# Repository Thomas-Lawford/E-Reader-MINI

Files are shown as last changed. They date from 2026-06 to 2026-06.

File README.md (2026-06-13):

Solar Powered E-Reader Keychain 

Has a custom E-Paper driver circuit MicroSD card interface and solar energy harvesting circuit.

Based on the STM32U073 with sub 1 μW operational power consumption.

Has a custom FILEX implementation that supports EXfat and fat32 file systems (Supports SDUC, SDXC and SDHC), 3d printed Case design and a custom EPD lookup table for the 1.22 inch E paper display.

Power consumption is so low this design is battery free with a supercap to store charge for brief current spikes from microSD card reads.
 
 You can select a text file to read, jump to a specific page, and adjust the font size
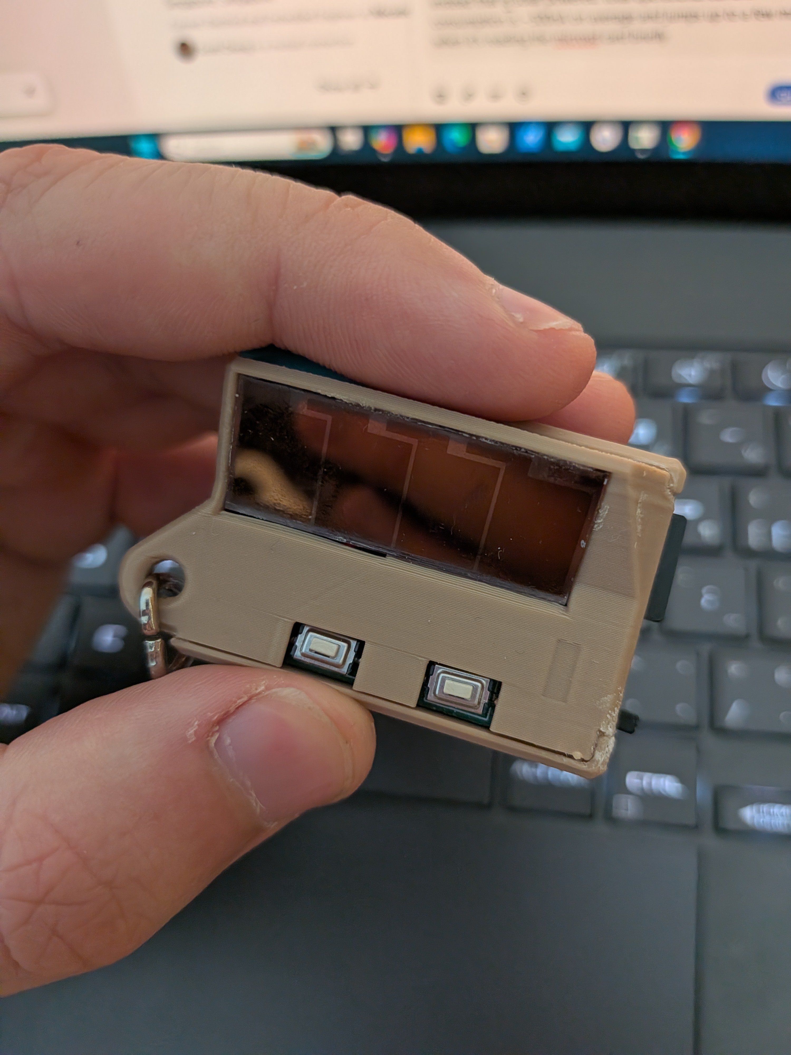
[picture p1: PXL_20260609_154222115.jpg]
back of device
 
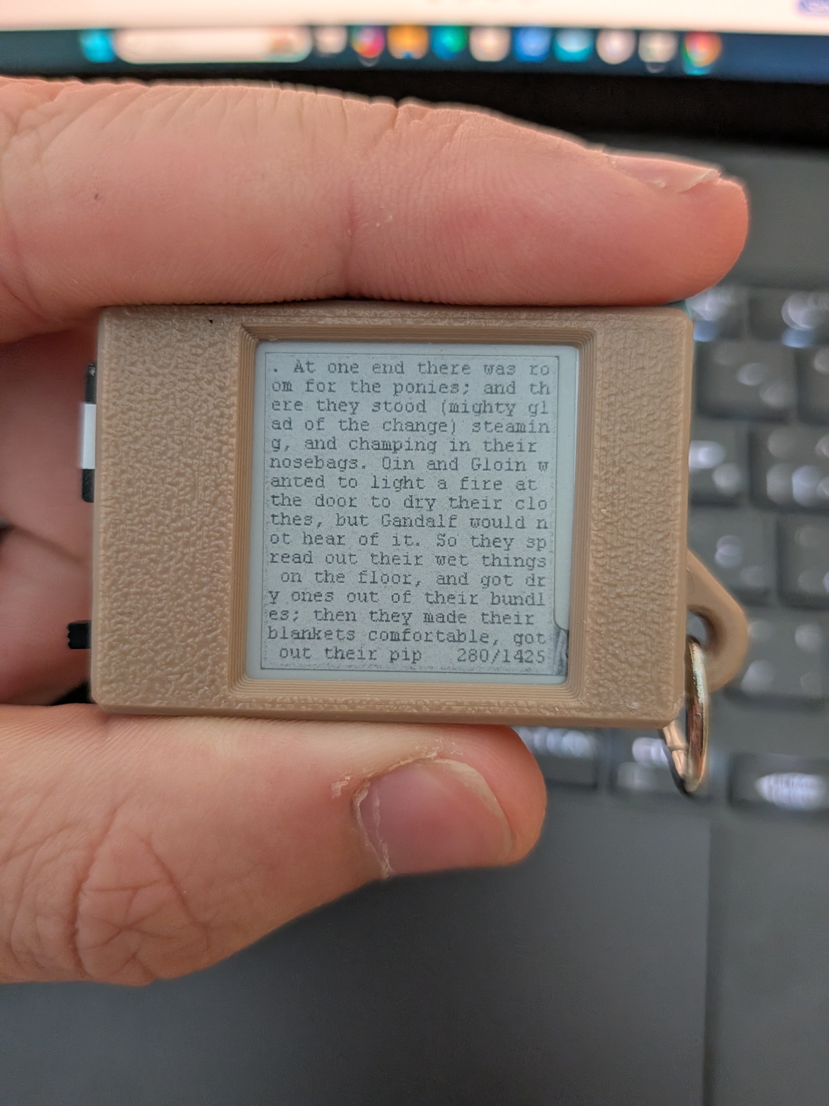
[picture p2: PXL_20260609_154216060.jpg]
front of device
 
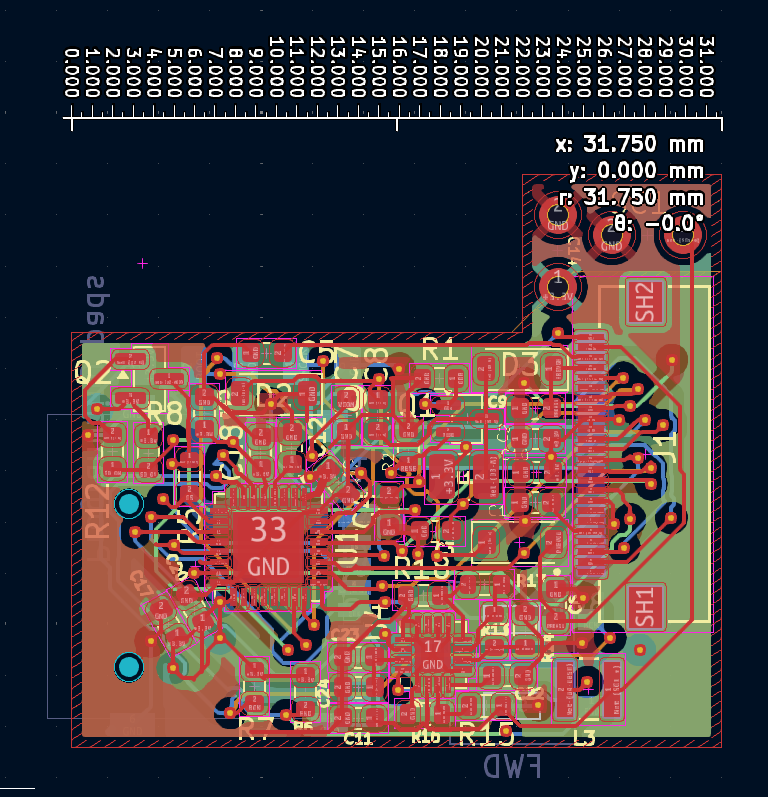
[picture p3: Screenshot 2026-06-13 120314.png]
PCB design


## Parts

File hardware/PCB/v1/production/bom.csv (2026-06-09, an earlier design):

Designator | Footprint | Quantity | Value | LCSC Part #
C1, C2, C3, C4, C5, C6, C7, C9 | 0603 | 8 | 1u 25v x5r/x7r
C10, C8 | 0603 | 2 | 4.7u 25v x5r/x7r
C11, C17, C24 | 0603 | 3 | 4.7uF
C12, C20, C21, C23 | 0603 | 4 | 100nf
C14 | 25F 3.8V cap | 1 | 25F
C18, C22 | 0603 | 2 | 10nf
C19 | 0603 | 1 | 1uf
D1, D2, D3 | D_SOD-123 | 3 | MBR0530
D4 | 0805 | 1 | LED
J1 | AMPHENOL_F33Z-1A7Q1-E8C24 | 1 | Conn_01x24_MountingPin
J2 | CONN9_MSD-4-A_SSD | 1 | Micro_SD_Card
J4 | 4_p_SWD_prog | 1 | Programming pads
L1 | 1008 | 1 | 4.7u 500mA
L3 | IND_ASPI-0315FS-220M-T2 | 1 | 22uh
Q1 | SOT-323_SC-70 | 1 | Si1308EDL
Q2 | SOT-23 | 1 | PMOS
R1 | 0603 | 1 | 1M
R12, R6, R7 | 0603 | 3 | 150k
R13 | 0603 | 1 | 4.75M
R14 | 0603 | 1 | 5.49M
R15 | 0603 | 1 | 8M
R16 | 0603 | 1 | 12M
R17 | 0603 | 1 | 5.1M
R18 | 0603 | 1 | 4.75
R2, R3 | 0603 | 2 | 2.2M
R4, R8 | 0603 | 2 | 220
R5 | 0603 | 1 | 20k
SC1 | 25F 3.8V cap | 1 | Solar_Cell
SW1 | SW_Tactile_SPST_NO_Straight_CK_PTS636Sx25SMTRLFS | 1 | BCK
SW3 | SW_Tactile_SPST_NO_Straight_CK_PTS636Sx25SMTRLFS | 1 | FWD
SW4 | SW_SLW-864574-5A-RA-N-D | 1 | SW_SPST
U1 | QFN-32-1EP_5x5mm_P0.5mm_EP3.45x3.45mm | 1 | STM32U073K8Ux
U4 | VQFN-16-1EP_3x3mm_P0.5mm_EP1.68x1.68mm | 1 | BQ25504

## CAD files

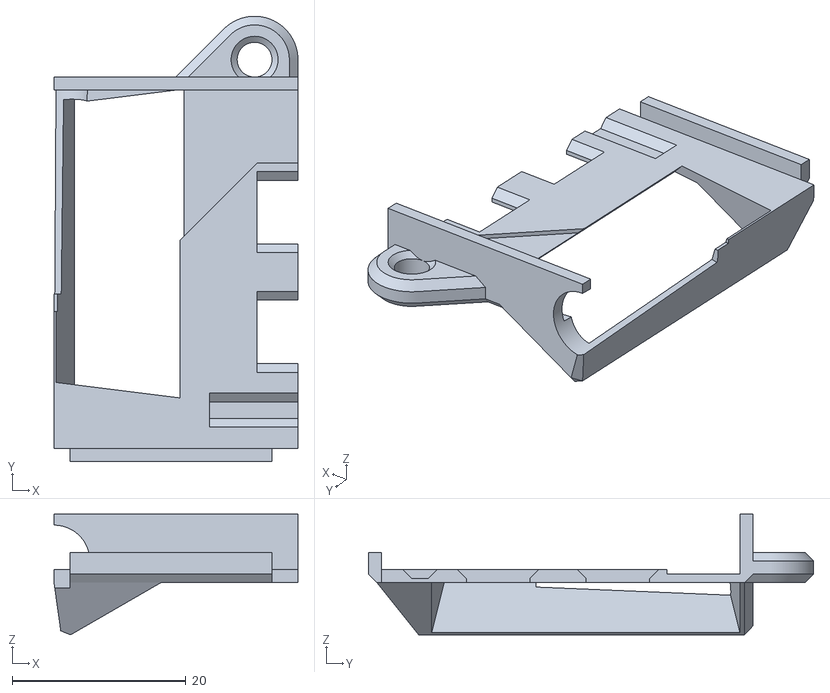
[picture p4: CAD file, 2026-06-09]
hardware/Case/v1/rear cover.stl
28.1 x 51.3 x 13.9

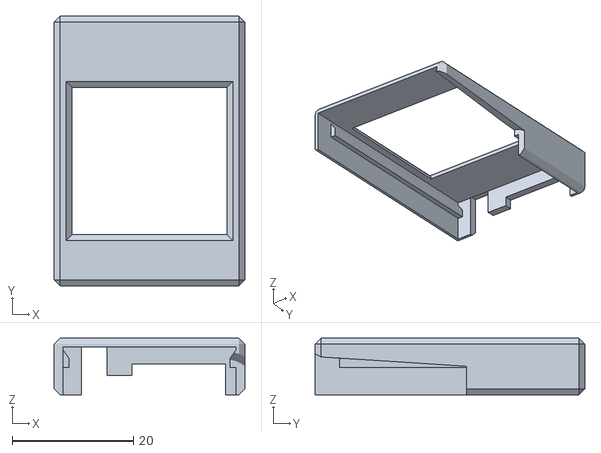
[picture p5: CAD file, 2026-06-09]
hardware/Case/v1/front cover.stl
31.5 x 44.5 x 9.40

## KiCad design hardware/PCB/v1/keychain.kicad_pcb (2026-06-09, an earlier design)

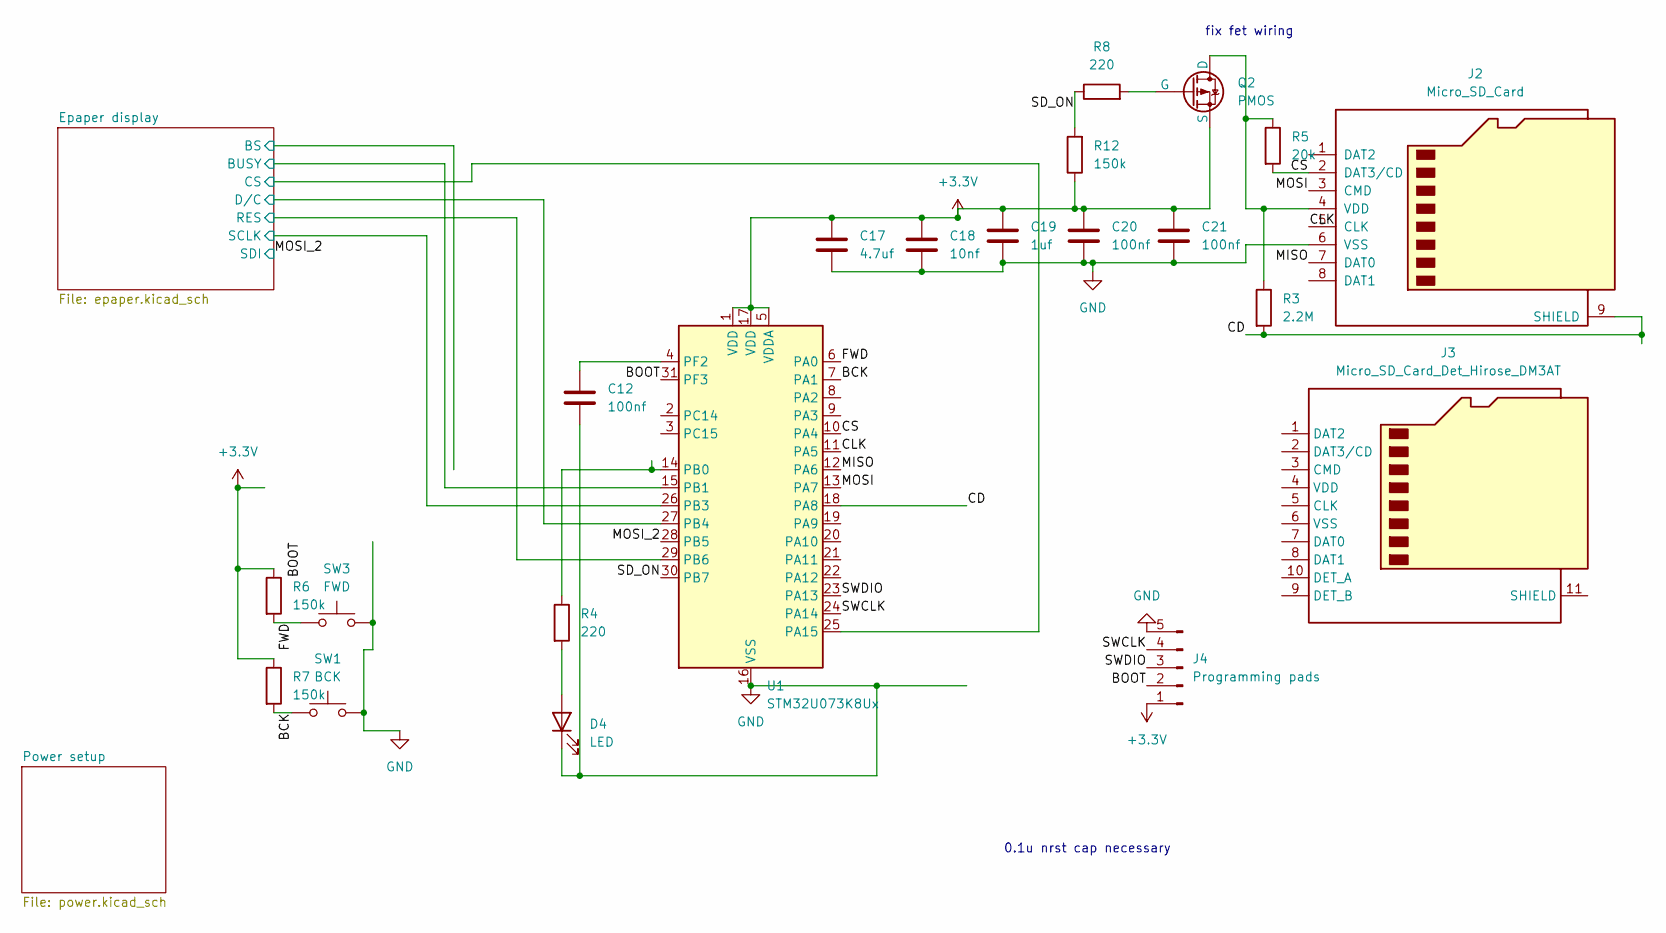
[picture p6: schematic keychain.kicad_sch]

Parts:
C12, C20, C21: 100nf; C_0603_1608Metric
C17: 4.7uf; C_0603_1608Metric
C18: 10nf; C_0603_1608Metric
C19: 1uf; C_0603_1608Metric
D4: LED; LED_0805_2012Metric
J2: Micro_SD_Card; CONN9_MSD-4-A_SSD
J3: Micro_SD_Card_Det_Hirose_DM3AT
J4: Programming pads; 4_p_SWD_prog
Q2: PMOS; SOT-23
R3: 2.2M; R_0603_1608Metric
R4, R8: 220; R_0603_1608Metric
R5: 20k; R_0603_1608Metric
R6, R7, R12: 150k; R_0603_1608Metric
SW1: BCK; SW_Tactile_SPST_NO_Straight_CK_PTS636Sx25SMTRLFS
SW3: FWD; SW_Tactile_SPST_NO_Straight_CK_PTS636Sx25SMTRLFS
U1: STM32U073K8Ux; QFN-32-1EP_5x5mm_P0.5mm_EP3.45x3.45mm

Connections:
+3.3V: C17.1, C18.1, C19.1, C20.1, C21.1, J4.1, Q2.3 (S), R6.1, R7.1, R12.1, U1.1 (VDD), U1.5 (VDDA), U1.17 (VDD); also elsewhere on the board
/BCK: R7.2, SW1.1, U1.7 (PA1)
/BOOT: J4.2, U1.31 (PF3)
/CD: J2.9 (SHIELD), R3.2, U1.18 (PA8)
/CLK: J2.5 (CLK), U1.11 (PA5)
/CS: J2.2 (DAT3/CD), R5.2, U1.10 (PA4)
/Epaper display/BUSY: U1.15 (PB1); also elsewhere on the board
/Epaper display/CS: U1.25 (PA15); also elsewhere on the board
/Epaper display/D/C: U1.27 (PB4); also elsewhere on the board
/Epaper display/RES: U1.29 (PB6); also elsewhere on the board
/Epaper display/SCLK: U1.26 (PB3); also elsewhere on the board
/FWD: R6.2, SW3.1, U1.6 (PA0)
/MISO: J2.7 (DAT0), U1.12 (PA6)
/MOSI: J2.3 (CMD), U1.13 (PA7)
/MOSI_2: U1.28 (PB5); also elsewhere on the board
/SD_ON: R8.1, R12.2, U1.30 (PB7)
/SWCLK: J4.4, U1.24 (PA14)
/SWDIO: J4.3, U1.23 (PA13)
GND: C12.2, C17.2, C18.2, C19.2, C20.2, C21.2, D4.1 (K), J2.6 (VSS), J4.5, SW1.2, SW3.2, U1.16 (VSS), U1.32 (VSS), U1.33 (VSS); also elsewhere on the board
unnamed: D4.2 (A), R4.2
unnamed: J2.4 (VDD), Q2.1 (D), R3.1, R5.1
unnamed: Q2.2 (G), R8.2
unnamed: R4.1, U1.14 (PB0)
unnamed: C12.1, U1.4 (PF2)

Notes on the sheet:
fix fet wiring
0.1u nrst cap necessary

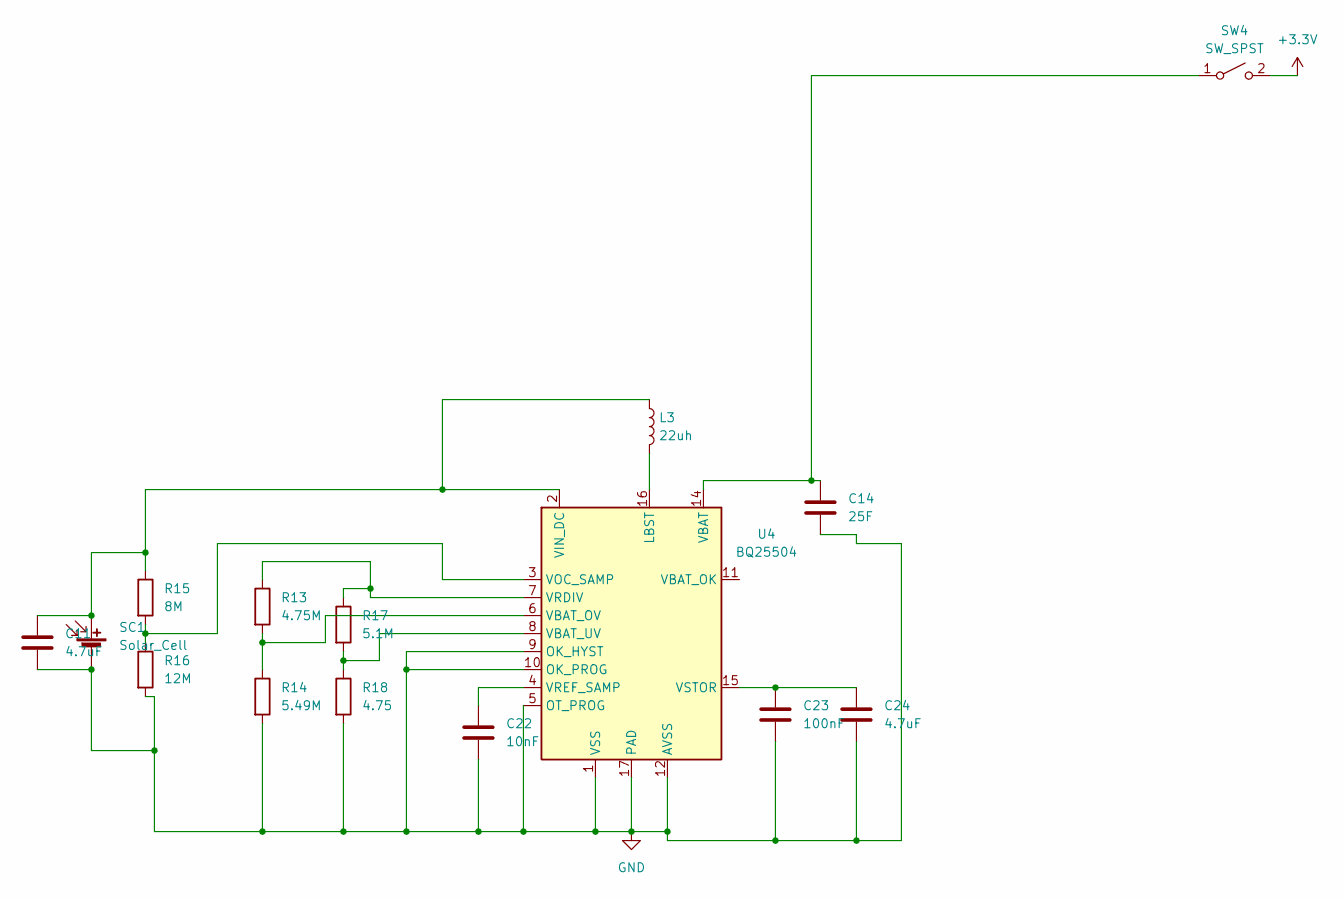
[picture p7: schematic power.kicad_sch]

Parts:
C11, C24: 4.7uF; C_0603_1608Metric
C14: 25F; 25F 3.8V cap
C22: 10nF; C_0603_1608Metric
C23: 100nF; C_0603_1608Metric
L3: 22uh; IND_ASPI-0315FS-220M-T2
R13: 4.75M; R_0603_1608Metric
R14: 5.49M; R_0603_1608Metric
R15: 8M; R_0603_1608Metric
R16: 12M; R_0603_1608Metric
R17: 5.1M; R_0603_1608Metric
R18: 4.75; R_0603_1608Metric
SC1: Solar_Cell; 25F 3.8V cap
SW4: SW_SPST; SW_SLW-864574-5A-RA-N-D
U4: BQ25504; VQFN-16-1EP_3x3mm_P0.5mm_EP1.68x1.68mm

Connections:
+3.3V: SW4.2 (B); also elsewhere on the board
GND: C11.2, C14.2, C22.2, C23.2, C24.2, R14.2, R16.2, R18.2, SC1.2 (-), U4.1 (VSS), U4.5 (OT_PROG), U4.9 (OK_HYST), U4.10 (OK_PROG), U4.12 (AVSS), U4.13 (VSS), U4.17 (PAD); also elsewhere on the board
unnamed: C11.1, L3.1, R15.1, SC1.1 (+), U4.2 (VIN_DC)
unnamed: C14.1, SW4.1 (A), U4.14 (VBAT)
unnamed: L3.2, U4.16 (LBST)
unnamed: R13.2, R14.1, U4.6 (VBAT_OV)
unnamed: R17.2, R18.1, U4.8 (VBAT_UV)
unnamed: R15.2, R16.1, U4.3 (VOC_SAMP)
unnamed: R13.1, R17.1, U4.7 (VRDIV)
unnamed: C22.1, U4.4 (VREF_SAMP)
unnamed: C23.1, C24.1, U4.15 (VSTOR)

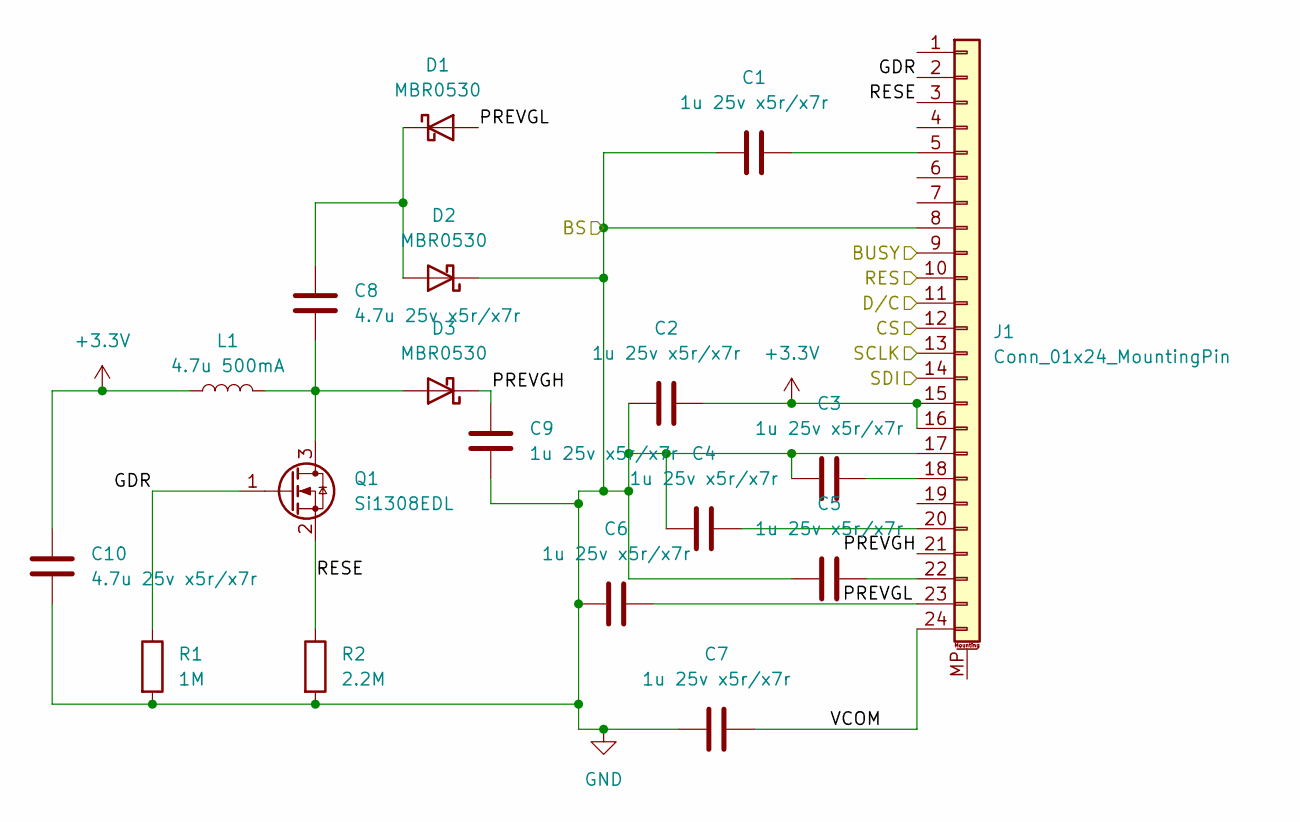
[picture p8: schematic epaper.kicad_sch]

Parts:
C1, C2, C3, C4, C5, C6, C7, C9: 1u 25v x5r/x7r; C_0603_1608Metric
C8, C10: 4.7u 25v x5r/x7r; C_0603_1608Metric
D1, D2, D3: MBR0530; D_SOD-123
J1: Conn_01x24_MountingPin; AMPHENOL_F33Z-1A7Q1-E8C24
L1: 4.7u 500mA; L_1008_2520Metric
Q1: Si1308EDL; SOT-323_SC-70
R1: 1M; R_0603_1608Metric
R2: 2.2M; R_0603_1608Metric

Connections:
+3.3V: C2.2, C10.2, J1.15, J1.16, L1.1; also elsewhere on the board
/Epaper display/BUSY: J1.9; also elsewhere on the board
/Epaper display/CS: J1.12; also elsewhere on the board
/Epaper display/D/C: J1.11; also elsewhere on the board
/Epaper display/GDR: J1.2, Q1.1 (G), R1.1
/Epaper display/PREVGH: C9.2, D3.1 (K), J1.21
/Epaper display/PREVGL: C6.2, D1.2 (A), J1.23
/Epaper display/RES: J1.10; also elsewhere on the board
/Epaper display/RESE: J1.3, Q1.2 (S), R2.1
/Epaper display/SCLK: J1.13; also elsewhere on the board
/Epaper display/VCOM: C7.2, J1.24
/MOSI_2: J1.14; also elsewhere on the board
GND: C1.1, C2.1, C3.1, C4.1, C5.1, C6.1, C7.1, C9.1, C10.1, D2.1 (K), J1.8, J1.17, R1.2, R2.2; also elsewhere on the board
unnamed: C8.1, D1.1 (K), D2.2 (A)
unnamed: C8.2, D3.2 (A), L1.2, Q1.3 (D)
unnamed: C1.2, J1.5
unnamed: C3.2, J1.18
unnamed: C4.2, J1.20
unnamed: C5.2, J1.22

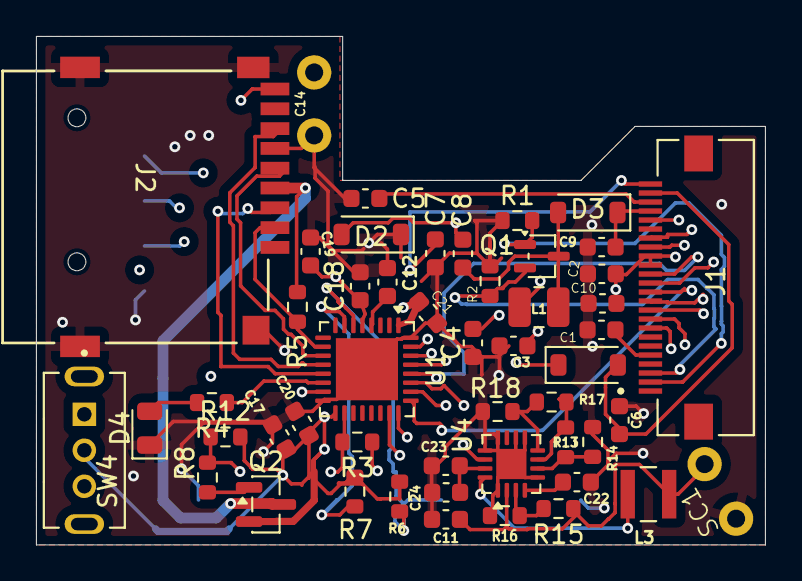
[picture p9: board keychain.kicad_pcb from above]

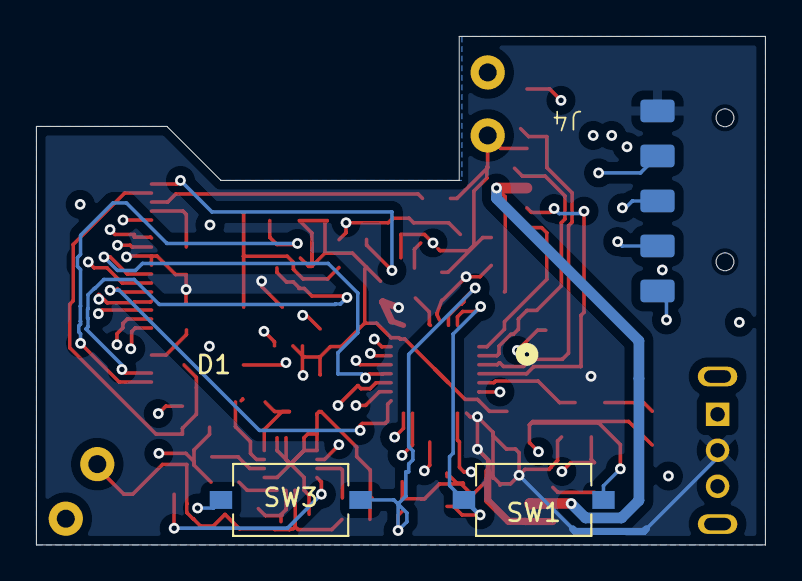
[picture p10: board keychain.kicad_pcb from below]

Board: 4 copper layers, 40.5 x 28.2 mm, 53 parts (3 on the bottom side), 44 nets.

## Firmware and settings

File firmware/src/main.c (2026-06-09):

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
/* Includes ------------------------------------------------------------------*/
#include "main.h"
#include "app_filex.h"

/* USER CODE BEGIN Includes */
#include "EPD/Display_EPD_W21.h"
#include "EPD/Display_EPD_W21_spi.h"
#include "GUI/GUI_Paint.h"
#include "Fonts/fonts.h"
//#include "fatfs.h"
//#include "spi.h"
//#include "sd_filereader.h"
#include "stdio.h"
//#include "sd_spi.h"
/* USER CODE END Includes */

/* USER CODE BEGIN PTD */
#define IMAGE_SIZE (EPD_WIDTH * EPD_HEIGHT / 8)
UBYTE ImageBuffer[IMAGE_SIZE];
/* USER CODE END PTD */

/* USER CODE BEGIN PD */
#define NDEBUG

// If using HAL, disable assert_param checks
#define USE_FULL_ASSERT 0
#define PVD_THRESHOLD_LEVEL  PWR_PVDLEVEL_4//4
#define COUNTER_BKP_REG     0   /* RTC->BKP0R = counter */
//#define STRING_BKP_START    1
#define BACKUP_STR_START   0   // BKP0R
#define BACKUP_STR_WORDS   16  // 64 bytes
//#define BACKUP_COUNTER     16  // BKP16R
#define BACKUP_page       17
#define BACKUP_menu       18

#define RETAINED_MAGIC 1
#define BACKUP_MAGIC     20
/* USER CODE END PD */


RTC_HandleTypeDef hrtc;

SPI_HandleTypeDef hspi1;

void SystemClock_Config(void);
static void MX_GPIO_Init(void);
static void MX_SPI1_Init(void);
static void MX_RTC_Init(void);
/* USER CODE BEGIN PFP */
/* Configure Wakeup pins */
/* FWD_Pin = PWR_WAKEUP_PIN1 (PA0) - falling edge (high to low) */
static void PVD_Config(void);
static void enter_standby(uint8_t high);
static void Configure_RTC_WakeupTimer(uint32_t seconds);
//static void SystemClock_Config_LowPower(void);
//static void SystemClock_Config_Normal(void);
//static void enable_backup_access(void);
/* USER CODE END PFP */

/**
  * @brief  The application entry point.
  * @retval int
  */
int main(void)
{

  /* USER CODE BEGIN 1 */
	//__HAL_RCC_SYS_DBGMCU_CLK_ENABLE();
	DBGMCU->CR = 0x00; // Disable all debug features

	/* Disable debug MCU in low-power modes (very impactful!) */
	//DBGMCU->CR &= ~DBGMCU_CR_DBG_SLEEP;
	DBGMCU->CR &= ~DBGMCU_CR_DBG_STOP;
	DBGMCU->CR &= ~DBGMCU_CR_DBG_STANDBY;

  /* USER CODE END 1 */

  /* MCU Configuration--------------------------------------------------------*/

  /* Reset of all peripherals, Initializes the Flash interface and the Systick. */
  HAL_Init();

  /* Configure the system clock */
  SystemClock_Config();

  /* Initialize all configured peripherals */
  MX_GPIO_Init();
  MX_SPI1_Init();
  MX_FileX_Init();
  MX_RTC_Init();
  /* USER CODE BEGIN 2 */
  __HAL_RCC_PWR_CLK_ENABLE();
  __HAL_RTC_WAKEUPTIMER_CLEAR_FLAG(&hrtc, RTC_FLAG_WUTF);
  unsigned int retained_magic;
  char     retained_string[28];
  unsigned int menu;
  unsigned int page;
  unsigned int num;
  unsigned int settings;
  unsigned int fontsize;
  unsigned int exits=0;
  //HAL_PWREx_EnableSRAMContentRetention();
  HAL_PWR_EnableBkUpAccess();
  //HAL_PWR_DisableWakeUpPin(PWR_WAKEUP_PIN1);
  retained_magic = READ_REG(TAMP->BKP8R);
  settings=((READ_REG(TAMP->BKP8R)&4)==4);
  num=(READ_REG(TAMP->BKP8R)&120)>>3;
  page=READ_REG(TAMP->BKP7R);
  menu=READ_REG(TAMP->BKP8R)&2;
  fontsize=READ_REG(TAMP->BKP6R);
  unsigned int temp=(READ_REG(TAMP->BKP8R)&896)>>7;
  //unsigned int EPDreset=
  unsigned int stuff =READ_REG(TAMP->BKP8R);
  uint8_t first_boot = ((retained_magic & 1) != 1);
  char    filenames[6][256];
  UINT    file_count = 0;
  while (__HAL_PWR_GET_FLAG(PWR_FLAG_VOSF)) { }
  PVD_Config();
  if (__HAL_PWR_GET_FLAG(PWR_FLAG_PVDO)){
	  EPD_HW_Init_CustomLUT();
	  Paint_NewImage(ImageBuffer, EPD_WIDTH, EPD_HEIGHT, ROTATE_270, WHITE);
	  Paint_SetMirroring(MIRROR_HORIZONTAL);
	  Paint_Clear(WHITE);
      Paint_DrawString_EN(10, 50, "LOW BATT", &Font16, WHITE, BLACK);
      EPD_SetRAMValue_BaseMap(ImageBuffer);
      EPD_DeepSleep(2);
      CLEAR_BIT(PWR->PDCRB, PWR_PDCRB_PD7);
      WRITE_REG(PWR->SCR, PWR_SCR_CWUF1 | PWR_SCR_CWUF3 | PWR_SCR_CSBF|RTC_SCR_CWUTF);
      HAL_PWR_EnterSHUTDOWNMode();   // never returns
  }
  if (first_boot){
	 /* EPD_GPIO_Init();
	/* uncomment only when ready
	  //EPD_HW_Init();
	  //EPD_HW_Init_Fast(0);
	  EPD_HW_Init_CustomLUT();
	  Paint_NewImage(ImageBuffer, EPD_WIDTH, EPD_HEIGHT, ROTATE_270, WHITE);
	  Paint_SetMirroring(MIRROR_HORIZONTAL);
	  Paint_Clear(WHITE);
  	char buf[100];
  	snprintf(buf, sizeof(buf), "HHIlo");
  	Paint_DrawString_EN(0, 10, buf, &Font24, WHITE, BLACK);
    EPD_SetRAMValue_BaseMap(ImageBuffer);
    EPD_DeepSleep(2);
    //SystemClock_Config_LowPower();
      //HAL_PWREx_EnableLowPowerRunMode();
      HAL_Delay(2000);
      //HAL_PWREx_DisableLowPowerRunMode();
      //SystemClock_Config_Normal();//*/
	  fontsize=2;
      menu=2;
	  page=0;
	  temp=0;
      //memset((void *)retained_string, 0, sizeof(retained_string));
      WRITE_REG(TAMP->BKP8R, 3);
      g_result=MX_FileX_GetTextFiles(filenames, &file_count);
      HAL_GPIO_WritePin(GPIOB, SD_ON_Pin, GPIO_PIN_SET);
   }
   uint32_t sr1 = READ_REG(PWR->SR1);  /* read before clearing */
   WRITE_REG(PWR->SCR, PWR_SCR_CWUF1 | PWR_SCR_CWUF3 | PWR_SCR_CSBF);

   if (!first_boot){

	   //int negtive=0;
       if ((sr1 & PWR_SR1_WUF1)==PWR_SR1_WUF1){//if fwd increment stuff   //HAL_GPIO_WritePin(GPIOB, GPIO_PIN_0, GPIO_PIN_SET);
    	  if(!settings){
    		  if(menu==2){
    			  temp=temp+1;
    		  }else{
        		  page=page+1;
    		  }
    	  }else{// if in settings increment number selector
    		  num=num+1;
    	  }

       }else if ((sr1 & PWR_SR1_WUF3)==PWR_SR1_WUF3){//back pin, decrement relevant value
       if(!settings){
    	  if(menu!=2){
    		  if (page!=0){
    	      page=page-1;}
    	  }else{
    		  temp=temp-1;
    	  }
       }else{
    		  num=num-1;
       }
       }else{//woken up by timer, release timer and sd card and long sleep
    	   //EPD_DeepSleep(2);
    	  HAL_RTCEx_DeactivateWakeUpTimer(&hrtc);
    	  enter_standby(1);}
       if(menu==2||settings){ //if menu
          if(menu==2){g_result=MX_FileX_GetTextFiles(filenames, &file_count);}else{SystemClock_Config_LowPower();
          HAL_PWREx_EnableLowPowerRunMode();
          HAL_Delay(70);
          HAL_PWREx_DisableLowPowerRunMode();
          SystemClock_Config_Normal();
          g_result=FX_SUCCESS;}
          //HAL_GPIO_WritePin(GPIOB, SD_ON_Pin, GPIO_PIN_SET);
          //SystemClock_Config_LowPower();
          //HAL_PWREx_EnableLowPowerRunMode();
          //HAL_Delay(300);
          //HAL_PWREx_DisableLowPowerRunMode();
          //SystemClock_Config_Normal();
        	if(HAL_GPIO_ReadPin(FWD_GPIO_Port, FWD_Pin) == GPIO_PIN_RESET){
        		menu=0;
        		if(!settings){//enter book
        			//HAL_GPIO_WritePin(GPIOB, GPIO_PIN_0, GPIO_PIN_SET);
        			  if (temp>file_count){///
        					temp=file_count;
        			  }
        			strncpy(filenames[0], filenames[temp-1], sizeof(filenames[temp-1]) - 1);
        			filenames[0][sizeof(filenames[temp-1]) - 2] = '\0';
        			temp=temp-1;
        			WRITE_REG(TAMP->BKP8R, 1|(temp<<7));
        		    page=0;
        		    fontsize=fontsize+1;
        		}else{//add page digit
        			num=num-1;
        			page=page*10+num;
        		}
        	}//fwd double press
        	if(HAL_GPIO_ReadPin(BCK_GPIO_Port, BCK_Pin) == GPIO_PIN_RESET){
        		menu=0;
        		if(!settings){//enter settings first time
	      	      	temp=temp+1;
	      	      	WRITE_REG(TAMP->BKP8R, (5|(temp<<7)));
        		    settings=1;
        		    page=0;
        		}else{//enter book and exit settings
      			  //if (temp>=file_count){///
      				//	temp=file_count-1;
      			  //}
      			g_result=MX_FileX_GetTextFiles(filenames, &file_count);
        			settings=0;//hangs here
        			WRITE_REG(TAMP->BKP8R, (1|(temp<<7)));
            		strncpy(filenames[0], filenames[temp], sizeof(filenames[temp]) - 1);
            		filenames[0][sizeof(filenames[temp]) - 1] = '\0';
            		fontsize=fontsize+2;
            		exits=1;
        		}
        	}//if double press back


       }// if menu


  }//not first boot
   if (settings){
		menu=0;//make sure settings gets drawn if in settings and not menu
	}
  WRITE_REG(TAMP->BKP7R, page);
  if(num>9){num=0;}

  //num=;
  WRITE_REG(TAMP->BKP8R, (num<<3)|(READ_REG(TAMP->BKP8R)&7)|(temp<<7));

   // paintsection no logic allowed below
  EPD_GPIO_Init();
  if(menu||settings){

	  //EPD_DeepSleep(0);
	  EPD_HW_Init_CustomLUT();
	  //EPD_HW_Init_Fast(5);
  }else{
	  //EPD_DeepSleep(0);
	  EPD_HW_Init_CustomLUT();
  //EPD_HW_Init_Fast(fontsize);
  }
// uncomment only when ready
  //EPD_HW_Init_Fast();
  Paint_NewImage(ImageBuffer, EPD_WIDTH, EPD_HEIGHT, ROTATE_270, WHITE);
  Paint_SetMirroring(MIRROR_HORIZONTAL);
  Paint_Clear(WHITE);

  if(menu==2){//draw menu
	  if (g_result == FX_SUCCESS){
		  for (int i =0; i<file_count; i++){
      		  char buf[256];
      	      snprintf(buf, sizeof(buf)," %s\r\n", filenames[i]);
      	      if (i==temp){Paint_DrawString_EN(0, 32*i, buf, &Font16, BLACK, WHITE);}else{
      	    	  Paint_DrawString_EN(0, 32*i, buf, &Font16, WHITE, BLACK);
      	      }
		  }
	  }else{
		  char buf[32];
      	  snprintf(buf, sizeof(buf), " SD error (%d)\r\n", g_result);
   		  Paint_DrawString_EN(10, 10, buf, &Font16, WHITE, BLACK);
   	      (void)g_result;
      }
  }else{//draw pages
		if(!settings){
			unsigned int up=0;
			unsigned int down=0;
		    //g_result=MX_FileX_GetTextFiles(filenames, &file_count);
	        SystemClock_Config_LowPower();
	          HAL_PWREx_EnableLowPowerRunMode();
	          HAL_Delay(70);
	          HAL_PWREx_DisableLowPowerRunMode();
	          SystemClock_Config_Normal();
	          g_result=FX_SUCCESS;
        	if(HAL_GPIO_ReadPin(FWD_GPIO_Port, FWD_Pin) == GPIO_PIN_RESET){

				fontsize=fontsize+1;
				up=1;
				if (fontsize>4){
					fontsize=4;
        	}
        	}
        	if(HAL_GPIO_ReadPin(BCK_GPIO_Port, BCK_Pin) == GPIO_PIN_RESET){
        		if(!exits){
        	    if (fontsize>0){fontsize=fontsize-1;}
        	    down=1;}
        	}
			WRITE_REG(TAMP->BKP6R, fontsize);

    		strncpy(filenames[0], filenames[temp], sizeof(filenames[temp]) - 1);
    		filenames[0][sizeof(filenames[temp]) - 1] = '\0';//*/
			if (g_result == FX_SUCCESS){//

				char buf[1000];
			    if (fontsize==0){
			    	if (down){
			    		page=((page+1)*389/829);
			    	}
				//MX_FileX_ReadRange(filenames[0],page*829, (page+1)*829);
			    	MX_FileX_ReadRange(temp,page*829, (page+1)*829);
				snprintf(buf, sizeof(buf)," %s\r\n", g_txt_preview);
				Paint_DrawString_EN(0, 0, buf, &Font8, WHITE, BLACK);
				Paint_DrawString_EN(0, 0, buf, &Font8, WHITE, BLACK);
				}else if (fontsize==1){
			    	if (down){
			    		page=((page+1)*181/389);
			    	}if (up){
						if (page!=0){page=page-1;}
						page=((page)*829/389);
					}
			    	//MX_FileX_ReadRange(filenames[0],page*389, (page+1)*389);
					MX_FileX_ReadRange(temp,page*389, (page+1)*389);
				snprintf(buf, sizeof(buf)," %s\r\n", g_txt_preview);
				Paint_DrawString_EN(0, 0, buf, &Font12, WHITE, BLACK);
				Paint_DrawString_EN(0, 0, buf, &Font12, WHITE, BLACK);

			    }else if (fontsize==2){
			    	if (down){
			    		page=((page+1)*97/181);
			    	}if (up){
						if (page!=0){page=page-1;}
			    		page=((page)*389/181);

					}
			    //	HAL_GPIO_WritePin(GPIOB, GPIO_PIN_0, GPIO_PIN_SET);
			    	//MX_FileX_ReadRange(filenames[0],page*181, (page+1)*181);
			    	MX_FileX_ReadRange(temp,page*181, (page+1)*181);
			    	snprintf(buf, sizeof(buf)," %s\r\n", g_txt_preview);

			    	Paint_DrawString_EN(0, 0, buf, &Font16, WHITE, BLACK);
				Paint_DrawString_EN(0, 0, buf, &Font16, WHITE, BLACK);
				}else if(fontsize==3){
					if (down){
						page=((page+1)*97/181);
					}if (up){
						if (page!=0){page=page-1;}
						page=((page)*181/97);
					}
					//HAL_GPIO_WritePin(GPIOB, GPIO_PIN_0, GPIO_PIN_SET);
					//MX_FileX_ReadRange(filenames[0],page*97, (page+1)*97);
					MX_FileX_ReadRange(temp,page*97, (page+1)*97);
					snprintf(buf, sizeof(buf)," %s\r\n", g_txt_preview);
				Paint_DrawString_EN(0, 0, buf, &Font20, WHITE, BLACK);
				Paint_DrawString_EN(0, 0, buf, &Font20, WHITE, BLACK);
				}else{
					if (up){
						if (page!=0){page=page-1;}
						page=((page)*97/69);
					}
					//MX_FileX_ReadRange(filenames[0],page*69, (page+1)*69);
					MX_FileX_ReadRange(temp,page*69, (page+1)*69);
				snprintf(buf, sizeof(buf)," %s\r\n", g_txt_preview);
				Paint_DrawString_EN(0, 0, buf, &Font24, WHITE, BLACK);
				Paint_DrawString_EN(0, 0, buf, &Font24, WHITE, BLACK);
			    }
				WRITE_REG(TAMP->BKP7R, page);

				(void)g_txt_filename;
				(void)g_txt_preview;
				if (g_result != FX_SUCCESS){
					char buf[32];
					snprintf(buf, sizeof(buf), "  SD error (%d)\r\n", g_result);
					Paint_DrawString_EN(10, 10, buf, &Font16, WHITE, BLACK);
					(void)g_result;
					WRITE_REG(TAMP->BKP8R, 0);
				}
			}else{//pretty sure it never gets here
			char buf[32];
			snprintf(buf, sizeof(buf), "  SD error (%d)\r\n", g_result);
				Paint_DrawString_EN(10, 10, buf, &Font16, WHITE, BLACK);
				(void)g_result;
				WRITE_REG(TAMP->BKP8R, 0);
			}
		}else{//draw settings
        	char buf[400];
        	snprintf(buf, sizeof(buf), " Go to page:(%d)\r\n", page);
        	Paint_DrawString_EN(0, 0, buf, &Font16, WHITE, BLACK);
        	for(int i =0; i<10; i++){
        		snprintf(buf, sizeof(buf), " %d\r\n", i);
        		if(num==i){Paint_DrawString_EN((16*i)+10, 30,buf, &Font16, BLACK, WHITE);
        	    }else{
        	    	Paint_DrawString_EN((16*i)+10, 30, buf, &Font16, WHITE, BLACK);
        	    }
        	}
        	snprintf(buf, sizeof(buf), " XS = 0.2182      S = 0.4653      M = 1.0000      L = 1.8660     XL = 2.6231");
        	Paint_DrawString_EN(0, 60, buf, &Font16, WHITE, BLACK);
        }
  }
  //EPD_Dis_PartAll(ImageBuffer);
  //EPD_WhiteScreen_ALL_Fast(ImageBuffer);
  EPD_SetRAMValue_BaseMap(ImageBuffer);
  EPD_DeepSleep(2);
  __HAL_RTC_WAKEUPTIMER_CLEAR_FLAG(&hrtc, RTC_FLAG_WUTF);
  Configure_RTC_WakeupTimer(40);
  enter_standby(0);


  /* USER CODE END 2 */

  /* Infinite loop */
  /* USER CODE BEGIN WHILE */
  while (1){
    /* USER CODE END WHILE */

    /* USER CODE BEGIN 3 */

  }
  /* USER CODE END 3 */
}

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
/* USER CODE BEGIN 4 */
static void PVD_Config(void)
{
    PWR_PVDTypeDef pvdConfig = {0};

    pvdConfig.PVDLevel = PWR_PVDLEVEL_4; //4  = ~2.6V threshold
    pvdConfig.Mode    = PWR_PVD_MODE_NORMAL; // polling mode, no interrupt/EXTI

    HAL_PWR_ConfigPVD(&pvdConfig);
    HAL_PWR_EnablePVD();
}
void SystemClock_Config_LowPower(void)
{
  RCC_OscInitTypeDef RCC_OscInitStruct = {0};
  RCC_ClkInitTypeDef RCC_ClkInitStruct = {0};

  /** Drop to voltage scale 2 (already set in your normal config, but be explicit) */
  HAL_PWREx_ControlVoltageScaling(PWR_REGULATOR_VOLTAGE_SCALE2);

  /** Switch MSI to 1 MHz (RCC_MSIRANGE_4)
   *  Valid LPR ranges: _0=100kHz, _1=200kHz, _2=400kHz, _3=800kHz, _4=1MHz, _5=2MHz
   *  LSI stays on if you need RTC/IWDG/LPTIM wakeup */
  RCC_OscInitStruct.OscillatorType      = RCC_OSCILLATORTYPE_LSI | RCC_OSCILLATORTYPE_MSI;
  RCC_OscInitStruct.LSIState            = RCC_LSI_ON;
  RCC_OscInitStruct.MSIState            = RCC_MSI_ON;
  RCC_OscInitStruct.MSICalibrationValue = RCC_MSICALIBRATION_DEFAULT;
  RCC_OscInitStruct.MSIClockRange       = RCC_MSIRANGE_0;  // 1 MHz
  RCC_OscInitStruct.PLL.PLLState        = RCC_PLL_NONE;    // PLL must be off for LPR
  if (HAL_RCC_OscConfig(&RCC_OscInitStruct) != HAL_OK)
  {
    Error_Handler();
  }

  /** AHB/APB dividers: keep at /1 so HCLK = 1 MHz */
  RCC_ClkInitStruct.ClockType      = RCC_CLOCKTYPE_HCLK | RCC_CLOCKTYPE_SYSCLK
                                   | RCC_CLOCKTYPE_PCLK1;
  RCC_ClkInitStruct.SYSCLKSource   = RCC_SYSCLKSOURCE_MSI;
  RCC_ClkInitStruct.AHBCLKDivider  = RCC_SYSCLK_DIV1;
  RCC_ClkInitStruct.APB1CLKDivider = RCC_HCLK_DIV1;

  /** At 1 MHz, zero flash wait states are needed */
  if (HAL_RCC_ClockConfig(&RCC_ClkInitStruct, FLASH_LATENCY_0) != HAL_OK)
  {
    Error_Handler();
  }

  /** NOW it's safe to enable Low Power Run mode */
  HAL_PWREx_EnableLowPowerRunMode();
}
void SystemClock_Config_Normal(void)
{
  /** Must disable LPR before raising the clock back up */
  if (HAL_PWREx_DisableLowPowerRunMode() != HAL_OK)
  {
    Error_Handler();
  }

  RCC_OscInitTypeDef RCC_OscInitStruct = {0};
  RCC_ClkInitTypeDef RCC_ClkInitStruct = {0};

  RCC_OscInitStruct.OscillatorType      = RCC_OSCILLATORTYPE_LSI | RCC_OSCILLATORTYPE_MSI;
  RCC_OscInitStruct.LSIState            = RCC_LSI_ON;
  RCC_OscInitStruct.MSIState            = RCC_MSI_ON;
  RCC_OscInitStruct.MSICalibrationValue = RCC_MSICALIBRATION_DEFAULT;
  RCC_OscInitStruct.MSIClockRange       = RCC_MSIRANGE_7;  // back to 16 MHz
  RCC_OscInitStruct.PLL.PLLState        = RCC_PLL_NONE;
  if (HAL_RCC_OscConfig(&RCC_OscInitStruct) != HAL_OK)
  {
    Error_Handler();
  }

  RCC_ClkInitStruct.ClockType      = RCC_CLOCKTYPE_HCLK | RCC_CLOCKTYPE_SYSCLK
                                   | RCC_CLOCKTYPE_PCLK1;
  RCC_ClkInitStruct.SYSCLKSource   = RCC_SYSCLKSOURCE_MSI;
  RCC_ClkInitStruct.AHBCLKDivider  = RCC_SYSCLK_DIV1;
  RCC_ClkInitStruct.APB1CLKDivider = RCC_HCLK_DIV1;

  /** Back to 1 wait state for 16 MHz */
  if (HAL_RCC_ClockConfig(&RCC_ClkInitStruct, FLASH_LATENCY_1) != HAL_OK)
  {
    Error_Handler();
  }
}
/** Call this to return to full 16 MHz operation */
static void Configure_RTC_WakeupTimer(uint32_t seconds)
{
    HAL_RTCEx_DeactivateWakeUpTimer(&hrtc);
HAL_Delay(1);//taiting for WUTWF=1

    // * RTC_WAKEUPCLOCK_CK_SPRE_16BITS selects the 1 Hz ck_spre source
    // * and gives a 16-bit counter → up to 65535 s range.
    // * Counter value = desired seconds - 1.
    //HAL_RTCEx_SetWakeUpTimer_IT()
    if (HAL_RTCEx_SetWakeUpTimer_IT(&hrtc,
                                    seconds - 1,
                                    RTC_WAKEUPCLOCK_CK_SPRE_16BITS, 1) != HAL_OK)
    {
        Error_Handler();
    }//*/
}
/* ------------------------------------------------------------------ */
static void enter_standby(uint8_t high)
{
    /* Clear any stale wakeup flags before arming */
    WRITE_REG(PWR->SCR, PWR_SCR_CWUF1 | PWR_SCR_CWUF3 | PWR_SCR_CSBF|RTC_SCR_CWUTF);

    SET_BIT(PWR->CR3, PWR_CR3_APC);
    if (high){//should be a
    	SET_BIT(PWR->PUCRA, PWR_PUCRA_PU15);
    	SET_BIT(PWR->PUCRB, PWR_PUCRB_PU6);
    	CLEAR_BIT(PWR->PDCRB, PWR_PDCRB_PD7);
    	//CLEAR_BIT(PWR->PUCRB, PWR_PUCRB_PU0);
    }else{
    	//SET_BIT(PWR->PUCRB, PWR_PUCRB_PU0);
    	//CLEAR_BIT(PWR->PUCRB, PWR_PUCRB_PB7);
    	SET_BIT(PWR->PUCRB, PWR_PUCRB_PU6);
    	SET_BIT(PWR->PUCRA, PWR_PUCRA_PU15);
    	SET_BIT(PWR->PDCRB, PWR_PDCRB_PD7);

        __HAL_RCC_GPIOB_CLK_ENABLE();
       // GPIOB->MODER = 0xFFFFFFFFU;
    }

    SET_BIT(PWR->CR3, PWR_CR3_EWUP1 | PWR_CR3_EWUP3);
    SET_BIT(PWR->CR4, PWR_CR4_WP1   | PWR_CR4_WP3);


    SET_BIT(PWR->CR3, PWR_CR3_RRS);

    /* Enter Standby — execution stops here; wakeup causes a system reset */
    HAL_PWR_EnableWakeUpPin(PWR_WAKEUP_PIN1);
    HAL_PWR_EnableWakeUpPin(PWR_WAKEUP_PIN3);

    __HAL_PWR_CLEAR_FLAG(PWR_FLAG_WU);
    HAL_SuspendTick();
    HAL_PWR_EnterSTANDBYMode();
}

void Backup_WriteString(const char *s) {
    uint32_t w;

        memcpy(&w, s + 0*4, 4);
        WRITE_REG(TAMP->BKP0R, w);
        memcpy(&w, s + 1*4, 4);
            WRITE_REG(TAMP->BKP1R, w);
            memcpy(&w, s + 2*4, 4);
                        WRITE_REG(TAMP->BKP2R, w);
                        memcpy(&w, s + 3*4, 4);
                                    WRITE_REG(TAMP->BKP3R, w);
                                    memcpy(&w, s + 4*4, 4);
                                                WRITE_REG(TAMP->BKP4R, w);
                                                memcpy(&w, s + 5*4, 4);
                                                            WRITE_REG(TAMP->BKP5R, w);//'\0' add at end?
                                                            memcpy(&w, s + 6*4, 4);
                                                                        WRITE_REG(TAMP->BKP6R, w);
}

void Backup_ReadString(char *s) {
    uint32_t w;
    for (int i = 0; i < 7; i++) {
        w = READ_REG(TAMP->BKP0R+i);
        memcpy(s + i*4, &w, 4);
    }

}
/* USER CODE END 4 */
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


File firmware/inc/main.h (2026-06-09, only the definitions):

#define FWD_Pin GPIO_PIN_0
#define FWD_GPIO_Port GPIOA
#define BCK_Pin GPIO_PIN_1
#define BCK_GPIO_Port GPIOA
#define SD_CS_Pin GPIO_PIN_4
#define SD_CS_GPIO_Port GPIOA
#define SD_SCK_Pin GPIO_PIN_5
#define SD_SCK_GPIO_Port GPIOA
#define SD_MISO_Pin GPIO_PIN_6
#define SD_MISO_GPIO_Port GPIOA
#define SD_MOSI_Pin GPIO_PIN_7
#define SD_MOSI_GPIO_Port GPIOA
#define DEBUG_LED_Pin GPIO_PIN_0
#define DEBUG_LED_GPIO_Port GPIOB
#define EPD_BUSY_Pin GPIO_PIN_1
#define EPD_BUSY_GPIO_Port GPIOB
#define SD_CD_Pin GPIO_PIN_8
#define SD_CD_GPIO_Port GPIOA
#define EPD_CS_Pin GPIO_PIN_15
#define EPD_CS_GPIO_Port GPIOA
#define EPD_SCK_Pin GPIO_PIN_3
#define EPD_SCK_GPIO_Port GPIOB
#define EPD_DC_Pin GPIO_PIN_4
#define EPD_DC_GPIO_Port GPIOB
#define EPD_MOSI_Pin GPIO_PIN_5
#define EPD_MOSI_GPIO_Port GPIOB
#define EPD_RES_Pin GPIO_PIN_6
#define EPD_RES_GPIO_Port GPIOB
#define SD_ON_Pin GPIO_PIN_7
#define SD_ON_GPIO_Port GPIOB

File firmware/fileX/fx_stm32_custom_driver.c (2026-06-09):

/**
 * @file    fx_stm32_custom_driver.c
 * @brief   FileX I/O driver for SPI SDHC on STM32U0
 *
 * Implements all FX_DRIVER_* requests by delegating to spi_sd.c.
 * Sector size is fixed at 512 bytes to match FAT requirements.
 */

#include "fx_stm32_custom_driver.h"
#include "spi_sd.h"
#include <string.h>

/* One 512-byte sector scratch buffer for BOOT_READ/WRITE */
static uint8_t fx_driver_sector_buf[512];
static uint32_t partition_lba_start=0;
VOID fx_stm32_custom_driver(FX_MEDIA *media_ptr)
{
    switch (media_ptr->fx_media_driver_request)
    {
        /* ------------------------------------------------------------------
         * INIT: initialise the SD card.
         * FileX calls this once when fx_media_open() is called.
         * ------------------------------------------------------------------ */
        case FX_DRIVER_INIT:
        {
            if (SD_Init() == SD_OK)
            {
                media_ptr->fx_media_driver_status = FX_SUCCESS;
            }
            else
            {
                media_ptr->fx_media_driver_status = FX_IO_ERROR;
            }
            break;
        }

        /* ------------------------------------------------------------------
         * UNINIT: nothing to do for SPI SD.
         * ------------------------------------------------------------------ */
        case FX_DRIVER_UNINIT:
        {
            media_ptr->fx_media_driver_status = FX_SUCCESS;
            break;
        }

        /* ------------------------------------------------------------------
         * BOOT READ: read sector 0 (the boot/MBR sector).
         * FileX reads this immediately after INIT to parse the FAT BPB.
         * ------------------------------------------------------------------ */
        case FX_DRIVER_BOOT_READ:
        {


            uint8_t sector0[512];
            if (SD_ReadSector(0, sector0) != SD_OK) {
                media_ptr->fx_media_driver_status = FX_IO_ERROR;

                break;
            }

            /* Check for MBR: 0x55AA signature + valid partition type in entry 1 */
            uint8_t part_type = sector0[446 + 4];
            uint16_t sig = (sector0[511] << 8) | sector0[510];

            if (sig == 0xAA55 && part_type != 0x00)
            {
                /* Extract LBA start of partition 1 (little-endian uint32 at offset 454) */
                uint32_t lba_start = (uint32_t)sector0[446 + 8]
                                   | ((uint32_t)sector0[446 + 9]  << 8)
                                   | ((uint32_t)sector0[446 + 10] << 16)
                                   | ((uint32_t)sector0[446 + 11] << 24);
                partition_lba_start=lba_start;

                /* Store so FX_DRIVER_READ can offset all subsequent sector accesses */
                media_ptr->fx_media_hidden_sectors = lba_start;

                /* Now read the actual boot sector */
                if (SD_ReadSector(lba_start, sector0) != SD_OK) {
                    media_ptr->fx_media_driver_status = FX_IO_ERROR;
                    break;

                }
                memcpy(media_ptr->fx_media_driver_buffer, sector0, 512);
            }
            else
            {
                /* No MBR — sector 0 is the BPB directly (superfloppy format) */
                memcpy(media_ptr->fx_media_driver_buffer, sector0, 512);
            }

            media_ptr->fx_media_driver_status = FX_SUCCESS;
           // HAL_GPIO_WritePin(GPIOB, GPIO_PIN_0, GPIO_PIN_SET);

            //HAL_GPIO_WritePin(GPIOB, GPIO_PIN_0, GPIO_PIN_SET);
            break;
        }

        /* ------------------------------------------------------------------
         * READ: read one or more contiguous logical sectors.
         * fx_media_driver_logical_sector  = first sector to read
         * fx_media_driver_sectors         = number of sectors
         * fx_media_driver_buffer          = destination buffer
         * ------------------------------------------------------------------ */
        case FX_DRIVER_READ:
        {//HAL_GPIO_WritePin(GPIOB, GPIO_PIN_0, GPIO_PIN_SET);
            uint32_t sector = media_ptr->fx_media_driver_logical_sector
                            + partition_lba_start;
            uint32_t count  = media_ptr->fx_media_driver_sectors;
            uint8_t *buf    = media_ptr->fx_media_driver_buffer;

            media_ptr->fx_media_driver_status = FX_SUCCESS;

            for (uint32_t i = 0; i < count; i++)
            {
                if (SD_ReadSector(sector + i, buf + (i * 512U)) != SD_OK)
                {
                    media_ptr->fx_media_driver_status = FX_IO_ERROR;
                    //HAL_GPIO_WritePin(GPIOB, GPIO_PIN_0, GPIO_PIN_SET);
                    break;

                }
            }
            break;
        }

        /* ------------------------------------------------------------------
         * BOOT WRITE: write sector 0.
         * ------------------------------------------------------------------ */
        case FX_DRIVER_BOOT_WRITE:
        {
            if (SD_WriteSector(0, media_ptr->fx_media_driver_buffer) == SD_OK)
            {
                media_ptr->fx_media_driver_status = FX_SUCCESS;
            }
            else
            {
                media_ptr->fx_media_driver_status = FX_IO_ERROR;

            }
            break;
        }

        /* ------------------------------------------------------------------
         * WRITE: write one or more contiguous logical sectors.
         * ------------------------------------------------------------------ */
        case FX_DRIVER_WRITE:
        {
            uint32_t      sector = media_ptr->fx_media_driver_logical_sector
                                 + media_ptr->fx_media_hidden_sectors;
            uint32_t      count  = media_ptr->fx_media_driver_sectors;
            const uint8_t *buf   = media_ptr->fx_media_driver_buffer;

            media_ptr->fx_media_driver_status = FX_SUCCESS;

            for (uint32_t i = 0; i < count; i++)
            {
                if (SD_WriteSector(sector + i, buf + (i * 512U)) != SD_OK)
                {
                    media_ptr->fx_media_driver_status = FX_IO_ERROR;
                    break;
                }
            }
            break;
        }

        /* ------------------------------------------------------------------
         * FLUSH: no write cache in this driver — nothing to do.
         * ------------------------------------------------------------------ */
        case FX_DRIVER_FLUSH:
        {
            media_ptr->fx_media_driver_status = FX_SUCCESS;
            break;
        }

        /* ------------------------------------------------------------------
         * ABORT: nothing to clean up.
         * ------------------------------------------------------------------ */
        case FX_DRIVER_ABORT:
        {
            media_ptr->fx_media_driver_status = FX_SUCCESS;
            break;
        }
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

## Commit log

2026-06-09 Added hardware related files
    Added case 3d model, PCB files and parts
    [bom.csv, designators.csv, epaper.kicad_sch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]
2026-06-13 added screenshot of most recent PCB design
2026-06-13 Add PCB design image to README

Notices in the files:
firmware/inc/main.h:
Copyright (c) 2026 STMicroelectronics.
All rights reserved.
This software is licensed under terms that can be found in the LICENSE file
